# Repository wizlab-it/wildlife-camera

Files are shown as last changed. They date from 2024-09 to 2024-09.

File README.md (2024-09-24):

# Wildlife Camera

Battery-powered wildlife camera.
Based on the ESP32-CAM board. Wi-Fi support.
Takes pictures when movements are detected via a PIR sensor.
Stores pictures on SD Card (if present) and sends them to Telegram (if Wi-Fi available).
Controlled via telegram commands (if Wi-Fi available).

Documentation is incomplete, sorry for that.

## Telegram API Reference

You need first to create a bot via the @BotFather telegram bot.
You can find many websites that explains how to do that.
Add these commands to the bot: /wakeup, /photo, /photoflash, /status, /blink

### Get Updates
#### Get all unconfirmed updates (max 100)
```
curl "https://api.telegram.org/bot{API_TOKEN}/getUpdates"
```
#### Get last unconfirmed update
```
curl "https://api.telegram.org/bot{API_TOKEN}/getUpdates?offset=-1"
```
#### Get updates starting from the specified one
```
curl "https://api.telegram.org/bot{API_TOKEN}/getUpdates?offset={OFFSET_ID}"
```
### Post Messages
```
curl -s -X POST "https://api.telegram.org/bot{API_TOKEN}/sendMessage" -d chat_id={CHAT_ID} -d text="{MESSAGE}"
```

## Required libraries
- CRC32 by Christopher Baker
- ArduinoJson by Benoit Blanchon
- UrlEncode by Masayuki

## Online references
- [Telegram bot API](https://core.telegram.org/bots/api)
- [Telegram getUpdates API command](https://telegram-bot-sdk.readme.io/reference/getupdates)
- [ESP32 Documentation](https://docs.espressif.com/projects/arduino-esp32/)

## Credits and references
Created by [WizLab.it](https://www.wizlab.it/)
GitHub: [wizlab-it/wildlife-camera](https://github.com/wizlab-it/wildlife-camera/)

## License
This program is free software: you can redistribute it and/or modify it under the terms of the GNU General Public License as published by the Free Software Foundation, either version 3 of the License, or (at your option) any later version.
This program is distributed in the hope that it will be useful, but WITHOUT ANY WARRANTY; without even the implied warranty of MERCHANTABILITY or FITNESS FOR A PARTICULAR PURPOSE. See the GNU General Public License for more details.
To get a copy of the GNU General Public License, see [http://www.gnu.org/licenses/](http://www.gnu.org/licenses/)

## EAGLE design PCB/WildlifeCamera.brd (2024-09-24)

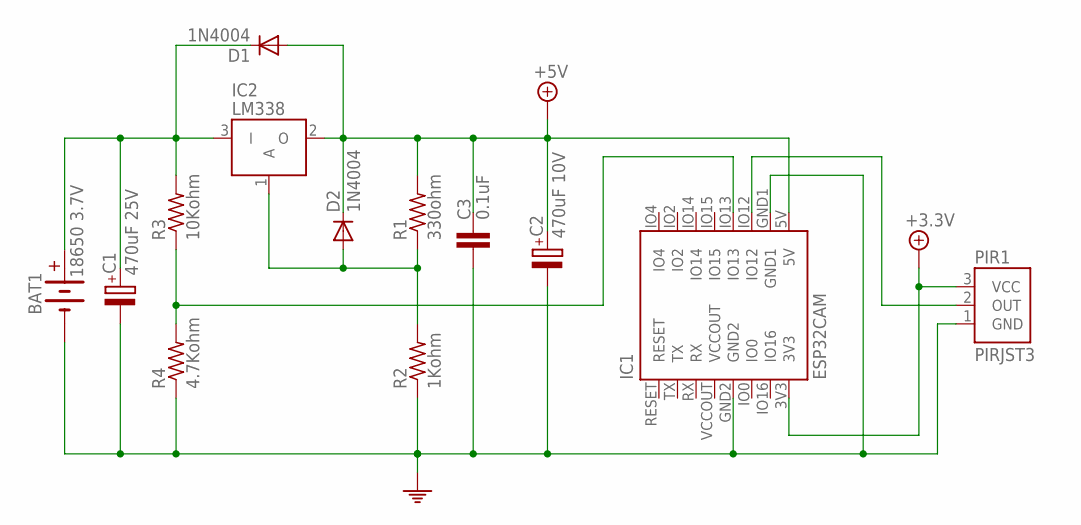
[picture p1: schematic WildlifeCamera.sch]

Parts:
BAT1: 18650 3.7V; SIL2
C1: 470uF 25V; CAPACITOR-5MM
C2: 470uF 10V; CAPACITOR-5MM
C3: 0.1uF; CAPACITOR-5MM
D1, D2: 1N4004; DIODE-BIG
IC1: ESP32CAM
IC2: LM338; TO220
PIR1: PIRJST3; JST3
R1: 330ohm; RESISTOR-0.25W
R2: 1Kohm; RESISTOR-0.25W
R3: 10Kohm; RESISTOR-0.25W
R4: 4.7Kohm; RESISTOR-0.25W

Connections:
+3.3V: IC1.3V3, PIR1.3 (VCC)
+5V: C2.1, C3.1, D1.A, D2.C, IC1.5V, IC2.2 (O), R1.2
GND: BAT1.2 (-), C1.2, C2.2, C3.2, IC1.GND1, IC1.GND2, PIR1.1 (GND), R2.1, R4.1
unnamed: BAT1.1 (+), C1.1, D1.C, IC2.3 (I), R3.2
unnamed: IC1.IO13, R3.1, R4.2
unnamed: D2.A, IC2.1 (A), R1.1, R2.2
unnamed: IC1.IO12, PIR1.2 (OUT)
VCCOUT: IC1.VCCOUT

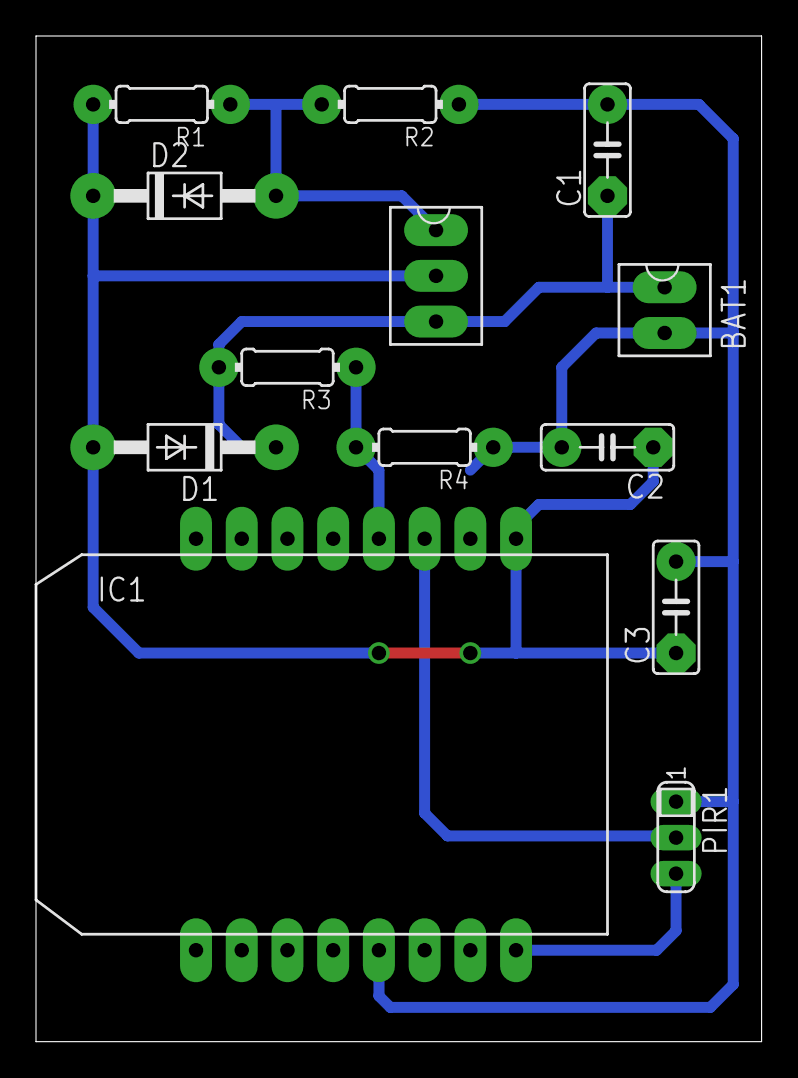
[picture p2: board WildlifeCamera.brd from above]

Board: 2 copper layers, 40.3 x 55.9 mm, 13 parts (0 on the bottom side), 7 nets.

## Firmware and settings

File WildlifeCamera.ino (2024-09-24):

/**
 * @package Wildlife Camera
 * @author WizLab.it
 * @board AI-Thinker ESP32-CAM
 * @version 20240826.126
 */

#include "WildlifeCamera.h"


/**
 * Global variables
 * Initialize Telegram communications and Camera
 */
Pir pir(PIR_ENABLED, PIR_PIN);
Telegram telegram(TELEGRAM_BOT_API_TOKEN, TELEGRAM_CHAT_ID, &telegramCommandProcessor);
Camera camera(CAMERA_FRAME_SIZE, CAMERA_QUALITY, CAMERA_SDCARD_ENABLED);


/**
 * PIR interrupt function
 */
void IRAM_ATTR pirInterrupt() {
  __PIR.motionDetected = true;
}


/**
 * Setup
 */
void setup() {
  WRITE_PERI_REG(RTC_CNTL_BROWN_OUT_REG, 0);

  //Start serial
  Serial.begin(115200);
  Serial.println(F("\n\n\n\n\n"));
  Serial.println(F("************************************************************************"));
  Serial.println(F("***               ~  Wildlife Camera - by WizLab.it  ~               ***"));
  Serial.println(F("************************************************************************"));
  Serial.println(F("[~~~~~] Setup:"));

  //Get wake up reason
  __WakeUp.reason = deepSleepWakeUpCheck();

  //Initialize camera and check if to take a photo (wake up by PIR)
  bool cameraStatus = camera.init();
  if(cameraStatus && (__WakeUp.reason == ESP_SLEEP_WAKEUP_EXT0)) {
    Serial.print(" [*] Take photo after PIR wake up... ");
    delay(1500);
    Serial.println("now");
    __PIR.photoLength = camera.takePhoto(&__PIR.photo, false);
  }

  //Configure built-in led
  pinMode(_LED_PIN, OUTPUT);
  digitalWrite(_LED_PIN, HIGH);

  //Configure lob-battery input pin
  pinMode(_LOWBATTERY_PIN, INPUT);

  //Connect to Wi-Fi
  wifiConnect(true);

  //Check if camera is available
  if(cameraStatus) {
    Serial.println(" [+] Camera activated");
    camera.sdOpen(); //Initiallize SD Card
    camera.sdClose();
  } else {
    Serial.println(" [-] Camera initialization");
    Serial.println(F("[~~~~~] Going to deep sleep..."));
    telegram.sendMessage("Camera initialization failed, going to sleep");
    deepSleepActivate(_DEEP_SLEEP_DURATION, true);
  }

  //Set wake up duration based on wake up reason
  switch(__WakeUp.reason) {
    case ESP_SLEEP_WAKEUP_EXT0: setWakeupEnd(_WAKEUP_DURATION_BY_PIR); break;
    case ESP_SLEEP_WAKEUP_TIMER: setWakeupEnd(_WAKEUP_DURATION_BY_TIMER); break;
    default: setWakeupEnd(_WAKEUP_DURATION_DEFAULT); break;
  }

  //Enable PIR
  if(PIR_ENABLED) pir.enable(&pirInterrupt);

  //Setup complete
  Serial.println(F("[~~~~~] Setup complete."));
  Serial.println(F("[~~~~~] Running:"));
}


/**
 * Loop
 */
void loop() {
  //If no photos are stored and PIR is enabled and motion is detected, then takes a new photo and calculate new wake up duration
  if(PIR_ENABLED && (__PIR.photo == NULL) && __PIR.motionDetected) {
    Serial.println(" [i] Motion detected, taking photo");
    __PIR.photoLength = camera.takePhoto(&__PIR.photo, false);
    setWakeupEnd(_WAKEUP_DURATION_BY_PIR);
    __PIR.motionDetected = false;
  }

  //Check WiFi connection
  if(wifiConnect(false)) {
    //Check if there is a photo to be sent on telegram
    if((__PIR.photoLength > 0) && (__PIR.photo != NULL)) {
      telegram.sendPhoto(__PIR.photo, __PIR.photoLength);
    }

    //Check Telegram updates every 5 seconds
    if(__Timers.telegramGetUpdates < millis()) {
      __Timers.telegramGetUpdates = millis() + 5000;
 
      //int8_t telegramUpdatesCount = telegramGetUpdates();
      int8_t telegramUpdatesCount = telegram.getUpdates();

      //If there are updates, then recalculate wake up duration
      if(telegramUpdatesCount > 0) setWakeupEnd(_WAKEUP_INCREASE_BY_TELEGRAM);
    }
  }

  //Battery level check
  batteryCheck();

  //Free PIR photo
  free(__PIR.photo);
  __PIR.photo = NULL;
  __PIR.photoLength = 0;

  //Check if go to deep sleep
  if(millis() > __WakeUp.end) {
    Serial.println(F("[~~~~~] Going to deep sleep..."));
    deepSleepActivate(_DEEP_SLEEP_DURATION, true);
  }

  //Loop end
  delay(500);
}


/**
 * wifiConnect
 * Connect to WiFi Network
 * @param blocking    if true, wait for connection result; if false, return immediately
 * @return            true if connection is successful, false otherwise
 */
bool wifiConnect(bool blocking) {
  bool wifiConnectionJustInitiated = false;

  //Check if already connected
  if(WiFi.status() == WL_CONNECTED) {
    //Get current timestamp
    long timestamp = getTimestamp();

    //Check if NTP is OK
    if(timestamp < 1000000000) {
      configTime((NTP_TIMEZONE * 3600), 3600, NTP_SERVER);
      timestamp = getTimestamp();
    }

    //Set startup timestamp
    if(__System.startupTimestamp == 0) {
      if(timestamp > 1000000000) {
        __System.startupTimestamp = timestamp - ((unsigned long)(millis() / 1000));
      }
    }

    return true;
  }

  //If here, it's not connected: if WiFi is OFF, then reset and start WiFi Connection
  wl_status_t wifiStatus = WiFi.status();
  if((wifiStatus != WL_NO_SHIELD) || (wifiStatus == WL_STOPPED)) {
    WiFi.disconnect(true);
    WiFi.mode(WIFI_STA);
    delay(250);
    WiFi.begin(WIFI_SSID, WIFI_PSK);
    wifiConnectionJustInitiated = true;
  }

  //Try to connect
  if(blocking) {
    Serial.printf(" [*] WiFi: connecting to %s: ", WIFI_SSID);
    uint8_t i = 0;
    while(WiFi.status() != WL_CONNECTED) {
      Serial.print(".");
      if(i++ > _WIFI_CONNECTION_TIMEOUT) break;
      delay(1000);
    }
    if(WiFi.status() == WL_CONNECTED) {
      Serial.println(" OK");
    } else {
      Serial.println(" failed");
      WiFi.disconnect(true);
    }
  } else {
    if(wifiConnectionJustInitiated) {
      __Timers.wifiConnectionTimeout = millis() + (_WIFI_CONNECTION_TIMEOUT * 1000);
      Serial.printf(" [*] WiFi: try to connect to %s (non-blocking)\n", WIFI_SSID);
    } else {
      if((WiFi.status() == WL_DISCONNECTED)) { //Connecting
        if(__Timers.wifiConnectionTimeout < millis()) {
          Serial.printf(" [-] WiFi: connection to %s failed\n", WIFI_SSID);
          WiFi.disconnect(true);
        }
      }
    }
  }

  //Check connection status
  if(WiFi.status() == WL_CONNECTED) {
    Serial.printf(" [+] WiFi: connected to %s (%s)\n", WIFI_SSID, WiFi.localIP().toString().c_str());

    //Set local time via NTP
    configTime((NTP_TIMEZONE * 3600), 3600, NTP_SERVER);

    return true;
  }

  //If here, connection failed
  return false;
}


/**
 * setWakeupEnd
 * Set new wake up end
 * End is changed only if larger than the current one
 * @param increase  How much the wake up duration should be increased
 * @return          Wake up end set
 */
unsigned long setWakeupEnd(unsigned long increase) {
  unsigned long newEnd = millis() + (increase * 1000);
  if(newEnd > __WakeUp.end) {
    __WakeUp.end = newEnd;
  }
  return __WakeUp.end;
}


/**
 * getTimestamp
 * Get current timestamp
 * @return    Current timestamp
 */
unsigned long getTimestamp() {
  struct tm timeinfo;
  time_t now;

  //Check NTP status
  if(!getLocalTime(&timeinfo)) {
    return (long)(millis() / 1000);
  }

  //Get current timestamp
  time(&now);
  return (now > 100000000) ? now : (long)(millis() / 1000);
}


/**
 * getDateFormat
 * Get formatted date
 * @param format      Format as defined for strftime()
 * @param timestamp   (optional) If set, use this timestamp, otherwise use current timestamp
 * @return            Formatted date as String
 */
String getDateFormat(String format, time_t timestamp) {
  struct tm timeinfo;
  time_t now;
  char datetime[50];

  //Check NTP status
  if(!getLocalTime(&timeinfo)) {
    return String("");
  }

  //Set time
  if(timestamp != 0) {
    now = timestamp;
  } else {
    time(&now);
    if(now < 100000000) return String("");
  }
  timeinfo = *localtime(&now);

  //Build string
  strftime(datetime, 50, format.c_str(), &timeinfo);
  return String(datetime);
}


/**
 * getUptime
 * Get uptime
 * @return    Uptime in seconds
 */
unsigned long getUptime() {
  if(__System.startupTimestamp != 0) {
    return (getTimestamp() - __System.startupTimestamp);
  } else {
    return (unsigned long)(millis() / 1000);
  }
}


/**
 * batteryCheck
 * General battery status check
 */
void batteryCheck() {
  //Battery level check (also update __System battery level variables)
  uint8_t batteryLevel = getBatteryLevel();

  if(batteryLevel < __System.batteryLastNotificationLevel) {
    Serial.println(" [*] Battery level: " + String(batteryLevel) + "/5");
    int8_t telegramStatus = telegram.sendMessage("Wildlife Camera battery status\n"
      " [+] Battery level: " + String(batteryLevel) + "/5 (" + String(_LOWBATTERY_NUMBER_OF_BATTERIES) + " batteries)\n"
      " [+] PIN voltage: " + String(__System.batteryVoltageMillivoltsOnAnalogPin / 1000.0) + "V\n"
      " [+] Pack voltage: " + String(__System.batteryVoltageMillivoltsEffective / 1000.0) + "V\n"
      " [+] Single voltage: " + String(__System.batteryVoltageMillivoltsEffective / (1000.0 * _LOWBATTERY_NUMBER_OF_BATTERIES)) + "V\n");
    if(telegramStatus == 0) __System.batteryLastNotificationLevel = batteryLevel;
  }

  //If battery is critically low, disable PIR and go to sleep for long time
  if(batteryLevel == 0) {
    Serial.println(" [~~~~~] Battery level critically low!\nSleeping for " + String(_LOWBATTERY_CRITICAL_DEEP_SLEEP) + " hours.");
    telegram.sendMessage("Wildlife Camera battery level critically low!\n"
      " [+] Battery level: " + String(batteryLevel) + "/5 (" + String(_LOWBATTERY_NUMBER_OF_BATTERIES) + " batteries)\n"
      " [+] PIN voltage: " + String(__System.batteryVoltageMillivoltsOnAnalogPin / 1000.0) + "V\n"
      " [+] Pack voltage: " + String(__System.batteryVoltageMillivoltsEffective / 1000.0) + "V\n"
      " [+] Single voltage: " + String(__System.batteryVoltageMillivoltsEffective / (1000.0 * _LOWBATTERY_NUMBER_OF_BATTERIES)) + "V\n"
      "Sleeping for " + String(_LOWBATTERY_CRITICAL_DEEP_SLEEP) + " hours.");
    deepSleepActivate(_LOWBATTERY_CRITICAL_DEEP_SLEEP * 60 * 60, false);
  }
}


/**
 * getBatteryVoltage
 * Get the battery voltage
 * @param getRaw    (optional, default true) If true, then return raw ADC result; if false, then returns millivolt
 * @return          Battery voltage (raw ADC or millivolts)
 */
uint32_t getBatteryVoltage(bool getRaw) {
  //Check if battery ADC needs to be updated
  if(__System.batteryVoltageCacheExpire < getTimestamp()) {
    __System.batteryVoltageCacheExpire = getTimestamp() + _LOWBATTERY_CACHE_TIMEOUT;

    //New battery ADC sample (disable WiFi when sampling)
    WiFi.disconnect(true);
    delay(1000);
    __System.batteryVoltageRaw = analogRead(_LOWBATTERY_PIN);
    delay(500);
    __System.batteryVoltageMillivoltsOnAnalogPin = analogReadMilliVolts(_LOWBATTERY_PIN);
    __System.batteryVoltageMillivoltsEffective = __System.batteryVoltageMillivoltsOnAnalogPin * _LOWBATTERY_VDIV_RATIO;  //Calculate effective battery voltage after voltage divider
    Serial.printf(" [i] Single battery voltage: %0.2fV (original: %0.2fV; raw: %d) (next sample on %s)\n", (__System.batteryVoltageMillivoltsEffective / (1000.0 * _LOWBATTERY_NUMBER_OF_BATTERIES)), (__System.batteryVoltageMillivoltsOnAnalogPin / (1000.0 * _LOWBATTERY_NUMBER_OF_BATTERIES)), (__System.batteryVoltageRaw / _LOWBATTERY_NUMBER_OF_BATTERIES), getDateFormat("%F, %T", __System.batteryVoltageCacheExpire).c_str());
    Serial.printf(" [i] %d-pack battery voltage: %0.2fV (original: %0.2fV; raw: %d) (next sample on %s)\n", _LOWBATTERY_NUMBER_OF_BATTERIES, (__System.batteryVoltageMillivoltsEffective / 1000.0), (__System.batteryVoltageMillivoltsOnAnalogPin / 1000.0), __System.batteryVoltageRaw, getDateFormat("%F, %T", __System.batteryVoltageCacheExpire).c_str());
    wifiConnect(true);

    //Set new wakeup duration
    setWakeupEnd(_WAKEUP_DURATION_DEFAULT);
  }

  return (getRaw) ? __System.batteryVoltageRaw : __System.batteryVoltageMillivoltsEffective;
}


/**
 * getBatteryLevel
 * Get battery level (0 to 5)
 * @return      Battery level (0-5)
 */
uint8_t getBatteryLevel() {
  uint32_t batteryVoltageMillivolts = getBatteryVoltage(false);

  //If battery voltage is <6000 mV, then it's connected to USB
  if(batteryVoltageMillivolts < (3000 * _LOWBATTERY_NUMBER_OF_BATTERIES)) return 5;

  //Battery Powered
  if(batteryVoltageMillivolts > (4000 * _LOWBATTERY_NUMBER_OF_BATTERIES)) return 5;
  else if(batteryVoltageMillivolts > (3900 * _LOWBATTERY_NUMBER_OF_BATTERIES)) return 4;
  else if(batteryVoltageMillivolts > (3800 * _LOWBATTERY_NUMBER_OF_BATTERIES)) return 3;
  else if(batteryVoltageMillivolts > (3700 * _LOWBATTERY_NUMBER_OF_BATTERIES)) return 2;
  else if(batteryVoltageMillivolts > (3600 * _LOWBATTERY_NUMBER_OF_BATTERIES)) return 1;
  else return 0;
}


/**
 * deepSleepActivate
 * Activate deep sleep
 * @param seconds             seconds to deep sleep before to wake up
 * @param enableWakeupByPir   if true, wake up by PIR is enabled; if false PIR won't wake up the device
 */
void deepSleepActivate(uint16_t seconds, bool enableWakeupByPir) {
  //Hold flash when sleeping
  camera.flashGpioHold(true);

  //PIR wake up
  pir.prepareDeepSleep(enableWakeupByPir);

  //Timer wake up
  esp_sleep_enable_timer_wakeup(seconds * 1000 * 1000);

  //Go to deep sleep
  gpio_deep_sleep_hold_en();
  esp_deep_sleep_start();
}


/**
 * deepSleepWakeUpCheck
 * Check if wake up from deep sleep
 * @return    Wake up reason
 */
esp_sleep_wakeup_cause_t deepSleepWakeUpCheck() {
  //Disable pin hold
  camera.flashGpioHold(false);
  gpio_deep_sleep_hold_dis();

  //Get wake up reason
  esp_sleep_wakeup_cause_t wakeup_reason = esp_sleep_get_wakeup_cause();
  switch(wakeup_reason) {
    case ESP_SLEEP_WAKEUP_EXT0: //Wake up from PIR
      Serial.println(" [*] Wake up by PIR (EXT0)");
      break;
    case ESP_SLEEP_WAKEUP_TIMER: //Wake up from TIMER
      Serial.println(" [*] Wake up by TIMER");
      break;
  }

  return wakeup_reason;
}


/**
 * cameraSdGetUsedSpace
 * Camera::sdGetUsedSpace() wrapper
 * @return    SD card usage percentage
 */
float cameraSdGetUsedSpace() {
  return camera.sdGetUsedSpace();
}


/**
 * telegramCommandProcessor
 * External function that processes the received telegram commands
 * ----------------------------------------
 * Telegram Bot commands list configuration
 * wakeup - Wake up from deep sleep
 * photo - Take a photo
 * photoflash - Take a photo with flash
 * status - Device status
 * blink - Blink flash (identify device)
 * ----------------------------------------
 * @param command     command string (i.e. /status)
 */
void telegramCommandProcessor(const char* command) {
  //Command: /wakeup
  //Send wake up welcome message
  if(strcmp("/wakeup", command) == 0) {
    setWakeupEnd(_WAKEUP_INCREASE_BY_TELEGRAM * 5);
    telegram.sendMessage("Hello!\nCurrent date and time: " + getDateFormat("%F, %T") + "\n\nI'll be awake for " + String(_WAKEUP_INCREASE_BY_TELEGRAM * 5 / 60) + " minutes, please send your commands");
  }

  //Command: /photo
  //Takes a photo and sent it to the telegram chat
  else if(strcmp("/photo", command) == 0) {
    uint8_t *photo = NULL;
    long photoLength = camera.takePhoto(&photo, false);
    if(photoLength > 0) telegram.sendPhoto(photo, photoLength);
    free(photo);
    photo = NULL;
  }

  //Command: /photoflash
  //Takes a photo with flash and sent it to the telegram chat
  else if(strcmp("/photoflash", command) == 0) {
    uint8_t *photo = NULL;
    long photoLength = camera.takePhoto(&photo, true);
    if(photoLength > 0) telegram.sendPhoto(photo, photoLength);
    free(photo);
    photo = NULL;
  }

  //Command: /status
  //Send device status
  else if(strcmp("/status", command) == 0) {
    String datetime = getDateFormat("%F, %T");
    String statusMessage = "Wildlife Camera by WizLab.it\n";

    //Calculate uptime parts
    unsigned long uptimeSeconds = getUptime();
    uint16_t uptimeHours = uint16_t(uptimeSeconds / 3600);
    uptimeSeconds -= (uptimeHours * 3600);
    uint8_t uptimeMinutes = uint8_t(uptimeSeconds / 60);
    uptimeSeconds -= (uptimeMinutes * 60);

    //Update battery voltages
    getBatteryVoltage(false);

    //Device status
    statusMessage += "\nDevice:\n"
      " [" + String((datetime == "") ? "-" : "+") + "] Date and time: " + ((datetime == "") ? "unknown" : datetime) + "\n"
      " [+] Uptime: " + String(uptimeHours) + " hours, " + String(uptimeMinutes) + " minutes, " + String(uptimeSeconds) + " seconds\n"
      " [+] Device ID: " + String(ESP.getEfuseMac()) + "\n";

    //WiFi status
    statusMessage += "\nWiFi:\n"
      " [+] SSID: " + WiFi.SSID() + "\n"
      " [+] RSSI: " + String(WiFi.RSSI()) + "\n"
      " [+] IP Address: " + String(WiFi.localIP().toString()) + "\n";

    //Battery status
    statusMessage += "\nBattery:\n"
      " [+] Level: " + String(getBatteryLevel()) + "/5\n"
      " [+] Quantity: " + String(_LOWBATTERY_NUMBER_OF_BATTERIES) + "\n"
      " [+] PIN voltage: " + String(__System.batteryVoltageMillivoltsOnAnalogPin / 1000.0) + "V\n"
      " [+] Pack voltage: " + String(__System.batteryVoltageMillivoltsEffective / 1000.0) + "V\n"
      " [+] Single voltage: " + String(__System.batteryVoltageMillivoltsEffective / (1000.0 * _LOWBATTERY_NUMBER_OF_BATTERIES)) + "V\n";

    //SD Card status
    statusMessage += "\nSD Card:\n";
    if(camera.sdOpen()) {
      statusMessage += " [+] Used space: " + String(camera.sdGetUsedSpace()) + "%\n"
        " [+] Number of photos: " + String(camera.sdGetPhotoCounter()) + "\n"
        " [+] Last photo date: " + ((camera.sdGetLastPhotoTimestamp() == 0) ? "-" : getDateFormat("%F, %T", camera.sdGetLastPhotoTimestamp())) + "\n";
    } else {
      statusMessage += " [-] not available\n";
    }
    camera.sdClose();

    //Send message
    telegram.sendMessage(statusMessage);
  }

  //Command: /blink
  //Blink the flash 5 times
  else if(strcmp("/blink", command) == 0) {
    for(uint8_t i=0; i<5; i++) {
      camera.flashBlink(10);
      delay(100);
    }
  }

  //Unknown command
  else {
    Serial.println(" [-] Unknown command");
  }
}

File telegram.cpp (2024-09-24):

/**
 * @package Wildlife Camera
 * Telegram support
 * @author WizLab.it
 * @version 20240308.087
 */

#include "telegram.h"


/**
 * Variables
 */
RTC_DATA_ATTR long __telegramLastUpdateId = -1;


/**
 * Telegram
 * Class constructor
 * @param apiToken    Telegram bot API token
 * @param chatId      Telegram Chat ID where to send messages
 * @param commandProcessorFunction    (optional) Pointer to the external function that process the received telegram commands
 */
Telegram::Telegram(String apiToken, int64_t chatId, void (*commandProcessorFunction)(const char*)) {
  _apiToken = apiToken;
  _chatId = chatId;
  _commandProcessorFunction = commandProcessorFunction;
}


/**
 * Telegram::getUpdates
 * Get updates on a telegram chat
 * @return    number of processed updates, negative value if error
 */
int8_t Telegram::getUpdates() {
  String payload = "offset=" + String(__telegramLastUpdateId);
  char* response;
  int8_t commStatus = _httpRequest(_TELEGRAM_COMMAND_GETUPDATES, (uint8_t*)(payload.c_str()), payload.length(), &response);
  int8_t updatesCount = 0;

  String logDatetime = getDateFormat("%F, %T");
  if(logDatetime == "") logDatetime = "Unknown date";
  Serial.printf("%s - Get telegram updates (from ID %ld): ", logDatetime.c_str(), __telegramLastUpdateId);
  if(commStatus == 0) {
    Serial.println("OK");

    //Parse response
    JsonDocument jsonParsed;
    deserializeJson(jsonParsed, response);

    //Process updates
    JsonArray updates = jsonParsed["result"].as<JsonArray>();
    if(updates.size() > 0) {
      for(JsonVariant update : updates) {
        long updateId = update["update_id"];
        const char* message = update["message"]["text"];

        //Set next Update ID
        __telegramLastUpdateId = updateId + 1;

        //Check if emssage is a command, then process it
        if(message[0] == '/') {
          strtok((char*)message, "@");
          Serial.printf(" [i] Received telegram command: %s\n", message);
          if(_commandProcessorFunction == NULL) {
            Serial.println(" [-] External command processor not defined");
          } else {
            _commandProcessorFunction(message);
          }
        }

        //Check max 10 updates per loop
        if(++updatesCount == 10) break;
      }
    }
  } else {
    Serial.printf("failed (err: %d)\n", commStatus);
  }

  //If commStatus is 0, then check was successful: returns number of processed updates
  if(commStatus == 0) return updatesCount;

  //If here, error during update: returns the error code
  return commStatus;
}


/**
 * Telegram::sendMessage
 * Send a message to a telegram chat
 * @param message   the message to send
 * @return          0 if successful, negative value if error
 */
int8_t Telegram::sendMessage(String message) {
  String payload = "chat_id=" + String(_chatId) + "&text=" + urlEncode(message);

  char* response;
  int8_t commStatus = _httpRequest(_TELEGRAM_COMMAND_MESSAGE, (uint8_t*)(payload.c_str()), payload.length(), &response);

  Serial.print(" [+] Send telegram message: ");
  if(commStatus == 0) {
    Serial.println("OK");
  } else {
    Serial.printf("failed (err: %d)\n", commStatus);
  }

  return commStatus;
}


/**
 * Telegram::sendAction
 * Send an action to a telegram chat
 * @param action    action to send (typing, upload_photo, record_video, upload_video, record_audio, upload_audio, upload_document, find_location)
 * @return          0 if successful, negative value if error
 */
int8_t Telegram::sendAction(String action) {
  String payload = "chat_id=" + String(_chatId) + "&action=" + action;
  char* response;
  int8_t commStatus = _httpRequest(_TELEGRAM_COMMAND_ACTION, (uint8_t*)(payload.c_str()), payload.length(), &response);
  return commStatus;
}


/**
 * Telegram::sendPhoto
 * Take a photo and send it to a telegram chat
 * @param photo         pointer to the photo data
 * @param photoLength   length of the photo data
 * @return              0 if successful, negative value if error
 */
int8_t Telegram::sendPhoto(uint8_t *photo, long photoLength) {
  //Check length
  if(photoLength < 1) return -1;

  //Send upload_photo action
  sendAction("upload_photo");

  //Prepare payload head and tail
  String caption = "Wildlife Camera photo on the " + getDateFormat("%F") + " at " + getDateFormat("%T") + "\r\nSD Used Space: " + String(cameraSdGetUsedSpace()) + "%";
  String payloadHead = "--" + String(_TELEGRAM_MULTIPART_BOUNDARY) + "\r\n"
    "Content-Disposition: form-data; name=\"chat_id\"; \r\n\r\n" + String(_chatId) + "\r\n--" + String(_TELEGRAM_MULTIPART_BOUNDARY) + "\r\n"
    "Content-Disposition: form-data; name=\"caption\"; \r\n\r\n" + caption + "\r\n--" + String(_TELEGRAM_MULTIPART_BOUNDARY) + "\r\n"
    "Content-Disposition: form-data; name=\"photo\"; filename=\"photo.jpg\"\r\nContent-Type: image/jpeg\r\n\r\n";
  String payloadTail = "\r\n--" + String(_TELEGRAM_MULTIPART_BOUNDARY) + "--\r\n";

  //Create payload
  long payloadLengthFinal = payloadHead.length() + photoLength + payloadTail.length(); //Calculate final payload length (head + image + tail)
  uint8_t *payload = (uint8_t *)malloc(payloadLengthFinal); //Allocate space for payload
  memcpy(payload, (uint8_t*)(payloadHead.c_str()), payloadHead.length()); //Add head to payload
  memcpy((payload + payloadHead.length()), photo, photoLength); //Add photo to payload
  memcpy((payload + payloadHead.length() + photoLength), (uint8_t*)(payloadTail.c_str()), payloadTail.length()); //Add tail to payload

  //Send request
  char* response;
  int8_t commStatus = _httpRequest(_TELEGRAM_COMMAND_PHOTO, payload, payloadLengthFinal, &response);
  Serial.print(" [+] Send telegram photo: ");
  if(commStatus == 0) {
    Serial.println("OK");
  } else {
    Serial.printf("failed (err: %d)\n", commStatus);
  }

  //Free payload and return
  free(payload);
  payload = NULL;
  return commStatus;
}
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

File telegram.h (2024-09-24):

/**
 * @package Wildlife Camera
 * Telegram support header
 * @author WizLab.it
 * @version 20240708.032
 */

#ifndef TELEGRAM_H
#define TELEGRAM_H


/**
 * Defines
 */
#define _TELEGRAM_HOSTNAME             "api.telegram.org"
#define _TELEGRAM_MULTIPART_BOUNDARY   "TelegramMultipartBoundary"
#define _TELEGRAM_WAIT_TIMEOUT         10

#define _TELEGRAM_COMMAND_GETUPDATES   1
#define _TELEGRAM_COMMAND_MESSAGE      2
#define _TELEGRAM_COMMAND_PHOTO        3
#define _TELEGRAM_COMMAND_ACTION       4


/**
 * Includes
 */
#include <Arduino.h>
#include <ArduinoJson.h>
#include <WiFi.h>
#include <WiFiClientSecure.h>
#include <UrlEncode.h>
#include "extern.h"


/**
 * Class definition
 */
class Telegram {
  private:
    String _apiToken;
    int64_t _chatId;
    void (*_commandProcessorFunction)(const char*); //Pointer to external command processor function

    int8_t _httpRequest(uint8_t command, uint8_t* payload, long payloadLength, char** responseToReturn);

  public:
    Telegram(String apiToken, int64_t chatId, void (*commandProcessorFunction)(const char*) = NULL);
    int8_t getUpdates();
    int8_t sendMessage(String message);
    int8_t sendPhoto(uint8_t *photo, long photoLength);
    int8_t sendAction(String action);
};


#endif
